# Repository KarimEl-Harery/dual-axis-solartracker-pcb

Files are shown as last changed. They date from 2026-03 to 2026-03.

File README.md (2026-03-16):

# Dual Axis Solar Tracker PCB

This repository contains the **PCB design and electronics for a mobile IoT-monitored dual-axis solar tracking system**.

The system automatically aligns a photovoltaic panel with the position of the sun to maximize solar energy generation.

The project combines **mechanical design, embedded systems, PCB development, and IoT communication**.

---

# 📄 Paper

The full project description is available in the paper:

➡️ **[Read the Paper](EMS-Gruppe%2016_STRZYZEWSKI_GAJIC_EL-Harery.pdf)**

---

# 🛰 Solar Tracker System

<p align="center">
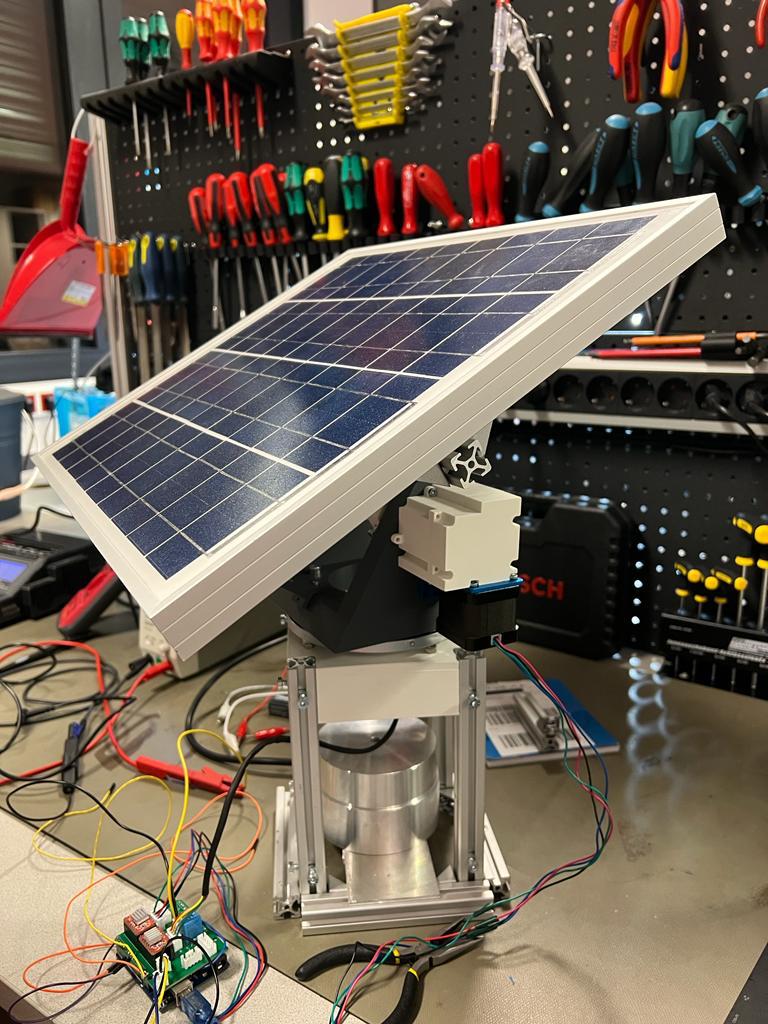
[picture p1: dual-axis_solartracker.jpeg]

</p>

The system uses an **Arduino Uno WiFi Rev2** to calculate the sun position based on GPS data and automatically align the photovoltaic panel using two motorized axes:

- **Azimuth rotation**
- **Altitude rotation**

The tracker communicates with an **IoT platform via WiFi using MQTT**.

---

# 🔌 PCB Design

The project includes a custom **Arduino Shield PCB** which integrates:

- Stepper motor control
- Sensor interfaces (light, temperature, GPS)
- Power management
- Communication interfaces

<p align="center">
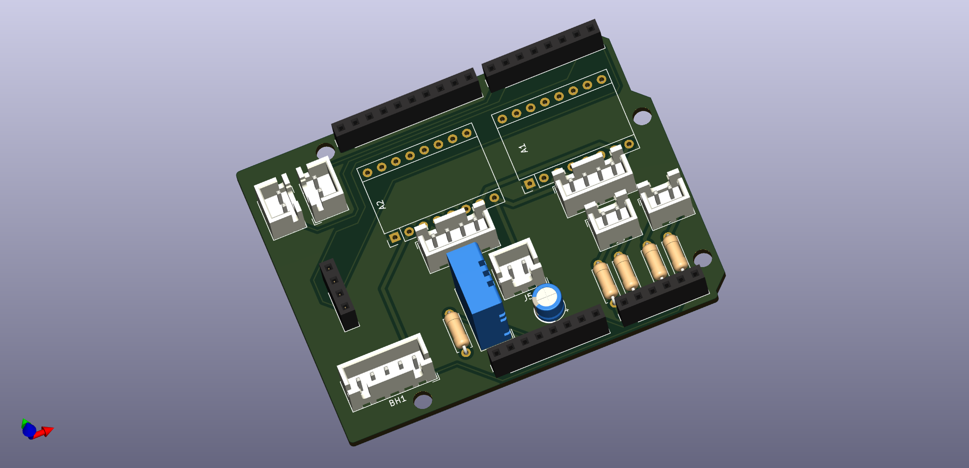
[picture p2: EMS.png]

</p>

---

# ⚙️ System Architecture

The solar tracker consists of three main subsystems:

### Embedded Control

- Arduino Uno WiFi Rev2
- Sun position calculation via library
- Stepper motor control
- Sensor data acquisition

### Electronics

Custom PCB providing:

- Motor driver interfaces
- Sensor connections
- GPS interface
- Power distribution

### Mechanical System

- **3D printed planetary gearbox** for altitude motion
- **Worm gear transmission** for azimuth motion
- Mobile solar platform

---

# 🌐 IoT Monitoring

System data is transmitted to an IoT platform via **WiFi using MQTT**.

Monitored parameters include:

- GPS position
- Solar panel orientation
- Illumination data
- Temperature
- System status

---

# 🔋 Power System

The system is powered by a **3S Li-Po battery (11.1V)** which is charged by the photovoltaic panel.

---

# 👨‍🔬 Authors  
Karim El-Harery

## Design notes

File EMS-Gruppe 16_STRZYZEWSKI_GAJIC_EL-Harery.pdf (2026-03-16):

# Mobiles IoT-überwachtes Solartracking-System

Patryk Strzyzewski, Milos Gajic, Karim El-Harery Fakultät Industrial Engineering, FH Technikum Wien, 1200 Wien

## Ergebnisse:

- Mobile Dual-Axis-Solar-Tracking-System
- 11,1V Lipo-Akku mit 3S-Konfiguration wird aufgeladen
- Aktueller Standort über GPS → Berechnung der Sonnenposition
- Steuerungen der Schrittmotoren über Arduino Uno Wifi Rev2
- Vertikale Drehung → 3D-gedrucktes Planetengetriebe
- Horizontale Drehung → Schneckengetriebe

## Einführung:

“Solar tracking system is a combination of electronics and mechanical system for aligning the Photovoltaic (PV) panels to the position of the sun [1]. ”

## Methoden:

## Ausblick:

Zu verbessern ist, dass ein Haltemoment mechanisch für die Azimut realisiert werden kann, damit es auch windresistent ist. Außerdem ist das Printed-Circuit-Board zu optimieren und neu herzustellen, da sie einige Fehler enthielt, diese wurden vorrübergehend mit Kabel gelöst. In Zukunft müsste auch die Schutzklasse erhöht werden. Statt Referenzschaltern, sind Encoder auch eine Möglichkeit, da dadurch die Position noch genauer bestimmbar ist [2].

Referenzen:
[1] J. F. Lee and N. A. Rahim, “Performance comparison of dual-axis solar tracker vs static solar system in Malaysia,” in 2013 IEEE Conference on Clean Energy and Technology (CEAT), Lankgkawi, Malaysia, 2013, pp. 102–107.
[2] KC Kim Consulting GmbH, “Encoder,” in . Accessed: Jan. 16 2024. [Online]. Available: https://www.kcco.com/de/glossar/encoder/

Konstruktion &
Getriebe

Daten in IoT-Plattform
Arduino Shield

Motorsteuerung

Sensorschnittstellen
(Belichtung, Temperatur,
GPS)

Arduino Uno Wifi-Rev-2

Sonnenberechnung über
Library

Verbindung über Wlan mit
MQTT

Azimuth-Bewegung

Altitude-Bewegung

Abb.2 Solartracker-Konstruktion

Abb.1 Programmtechnischer Prozessablauf des Solartracking-System

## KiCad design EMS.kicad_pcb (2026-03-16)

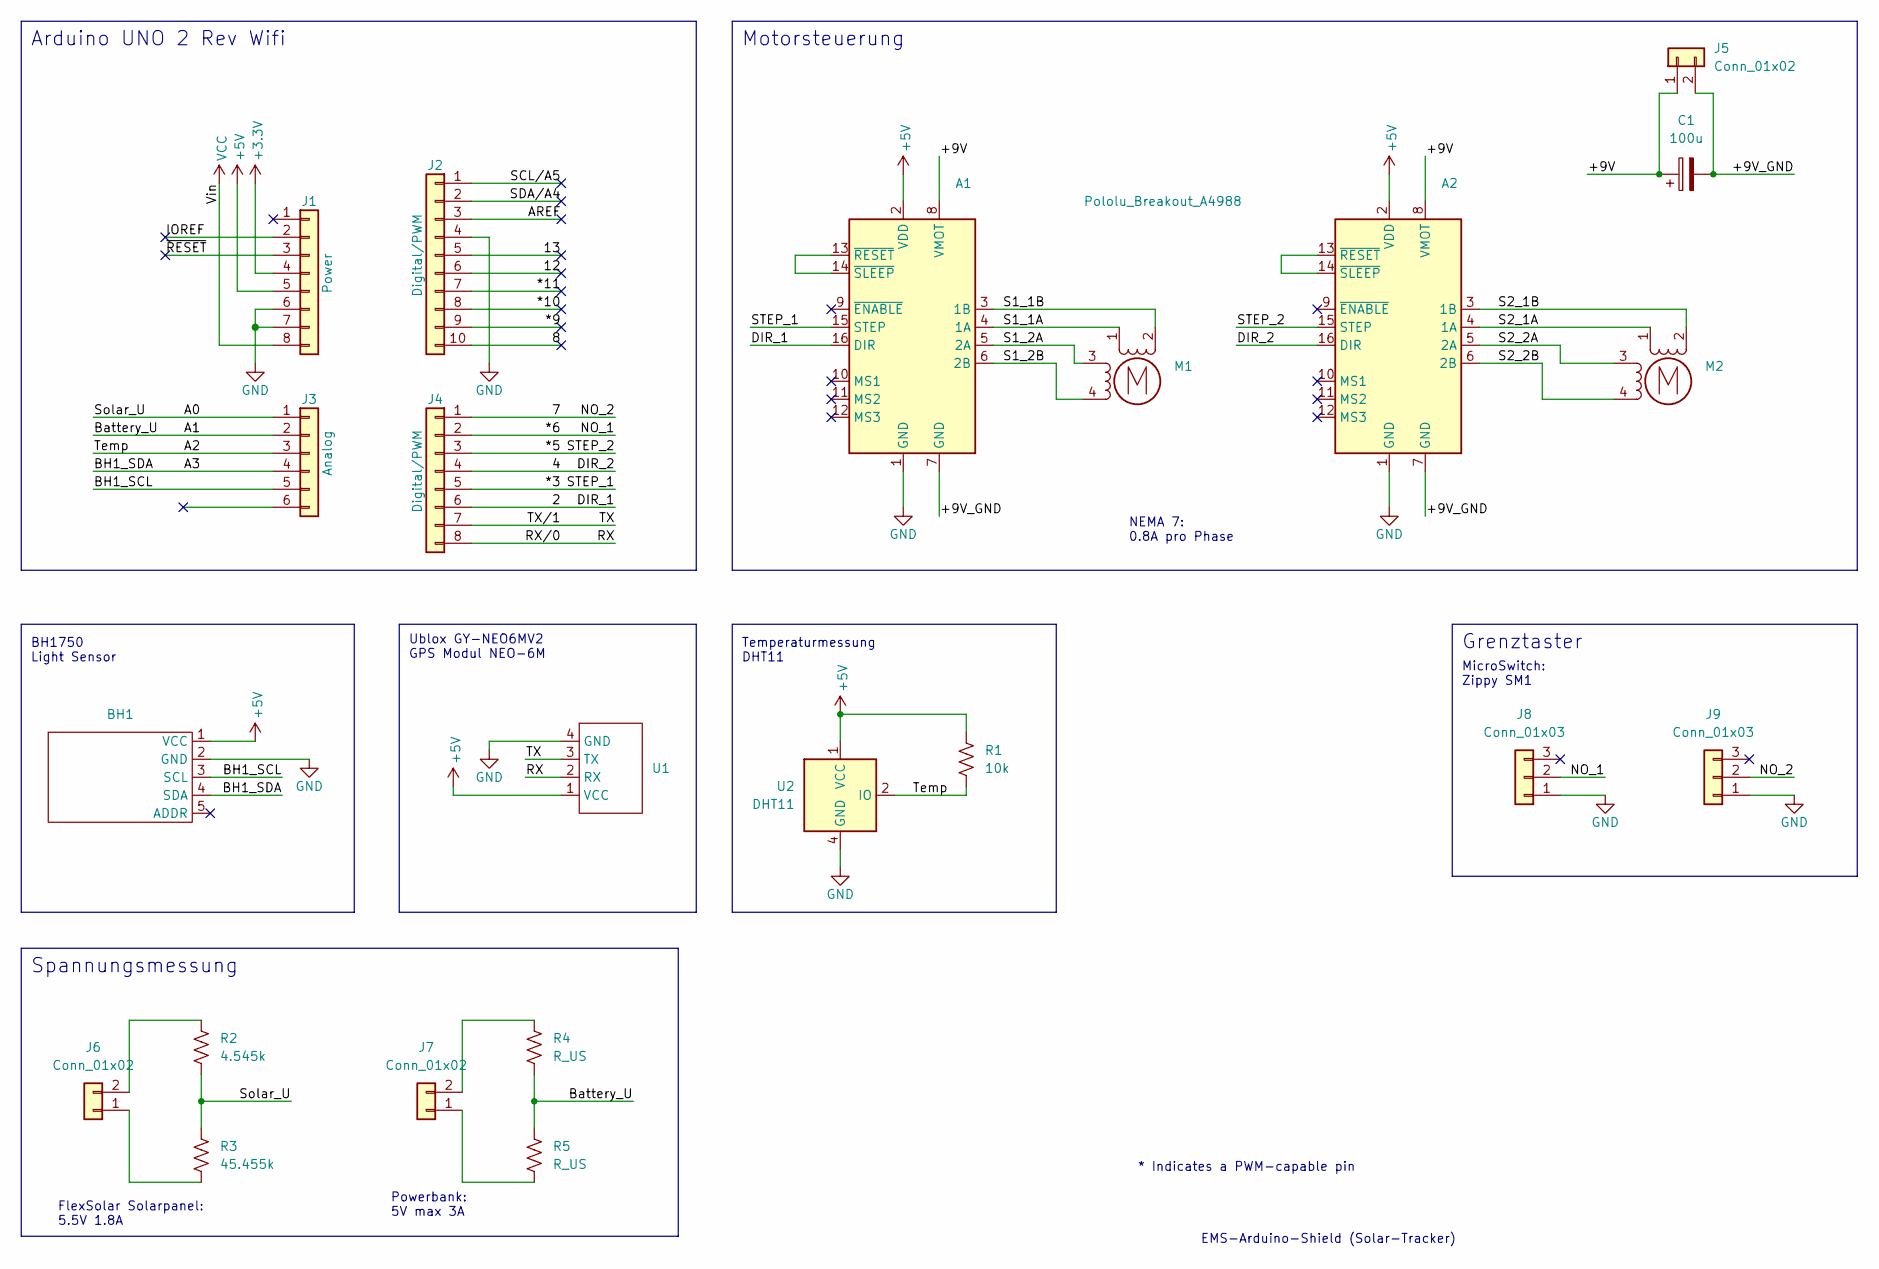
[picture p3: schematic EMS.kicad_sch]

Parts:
A1, A2: Pololu_Breakout_A4988; Pololu_Breakout-16_15.2x20.3mm
BH1: JST_XH_B5B-XH-A_1x05_P2.50mm_Vertical
C1: 100u; CP_Radial_D5.0mm_P2.50mm
J1: Power; PinSocket_1x08_P2.54mm_Vertical
J2: Digital/PWM; PinSocket_1x10_P2.54mm_Vertical
J3: Analog; PinSocket_1x06_P2.54mm_Vertical
J4: Digital/PWM; PinSocket_1x08_P2.54mm_Vertical
J5, J6, J7: Conn_01x02; JST_XH_B2B-XH-A_1x02_P2.50mm_Vertical
J8, J9: Conn_01x03; JST_XH_B2B-XH-A_1x02_P2.50mm_Vertical
M1, M2: Stepper_Motor_bipolar; JST_XH_B4B-XH-A_1x04_P2.50mm_Vertical
R1: 10k; R_Axial_DIN0207_L6.3mm_D2.5mm_P7.62mm_Horizontal
R2: 4.545k; R_Axial_DIN0207_L6.3mm_D2.5mm_P7.62mm_Horizontal
R3: 45.455k; R_Axial_DIN0207_L6.3mm_D2.5mm_P7.62mm_Horizontal
R4, R5: R_US; R_Axial_DIN0207_L6.3mm_D2.5mm_P7.62mm_Horizontal
U1: PinSocket_1x04_P2.54mm_Vertical
U2: DHT11; Aosong_DHT11_5.5x12.0_P2.54mm

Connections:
+3V3: J1.4
+5V: A1.2 (VDD), A2.2 (VDD), BH1.1 (VCC), J1.5, R1.1, U1.1 (VCC), U2.1 (VCC)
/2: A1.16 (DIR), J4.6
/4: A2.16 (DIR), J4.4
/7: J4.1, J9.2
/8: J2.10
/12: J2.6
/13: J2.5
/*3: A1.15 (STEP), J4.5
/*5: A2.15 (STEP), J4.3
/*6: J4.2, J8.2
/*9: J2.9
/*10: J2.8
/*11: J2.7
/+9V: A1.8 (VMOT), A2.8 (VMOT), C1.1, J5.1
/+9V_GND: A1.7 (GND), A2.7 (GND), C1.2, J5.2
/A0: J3.1, R2.2, R3.1
/A1: J3.2, R4.2, R5.1
/A2: J3.3, R1.2, U2.2 (IO)
/A3: BH1.4 (SDA), J3.4
/AREF: J2.3
/BH1_SCL: BH1.3 (SCL), J3.5
/IOREF: J1.2
/RX: J4.8, U1.2 (RX)
/S1_1A: A1.4 (1A), M1.1
/S1_1B: A1.3 (1B), M1.2 (-)
/S1_2A: A1.5 (2A), M1.3
/S1_2B: A1.6 (2B), M1.4
/S2_1A: A2.4 (1A), M2.1
/S2_1B: A2.3 (1B), M2.2 (-)
/S2_2A: A2.5 (2A), M2.3
/S2_2B: A2.6 (2B), M2.4
/SCL/A5: J2.1
/SDA/A4: J2.2
/TX: J4.7, U1.3 (TX)
/~RESET: J1.3
GND: A1.1 (GND), A2.1 (GND), BH1.2 (GND), J1.6, J1.7, J2.4, J8.1, J9.1, U1.4 (GND), U2.4 (GND)
unnamed: A1.13 (~RESET), A1.14 (~SLEEP)
unnamed: A2.13 (~RESET), A2.14 (~SLEEP)
unnamed: J6.1, R3.2
unnamed: J6.2, R2.1
unnamed: J7.1, R5.2
unnamed: J7.2, R4.1
VCC: J1.8

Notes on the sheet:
BH1750 Light Sensor
Temperaturmessung DHT11
EMS-Arduino-Shield (Solar-Tracker)
MicroSwitch: Zippy SM1
Spannungsmessung
FlexSolar Solarpanel: 5.5V 1.8A
Ublox GY-NEO6MV2 GPS Modul NEO-6M
NEMA 7: 0.8A pro Phase
Powerbank: 5V max 3A
Motorsteuerung
Arduino UNO 2 Rev Wifi
* Indicates a PWM-capable pin
Grenztaster

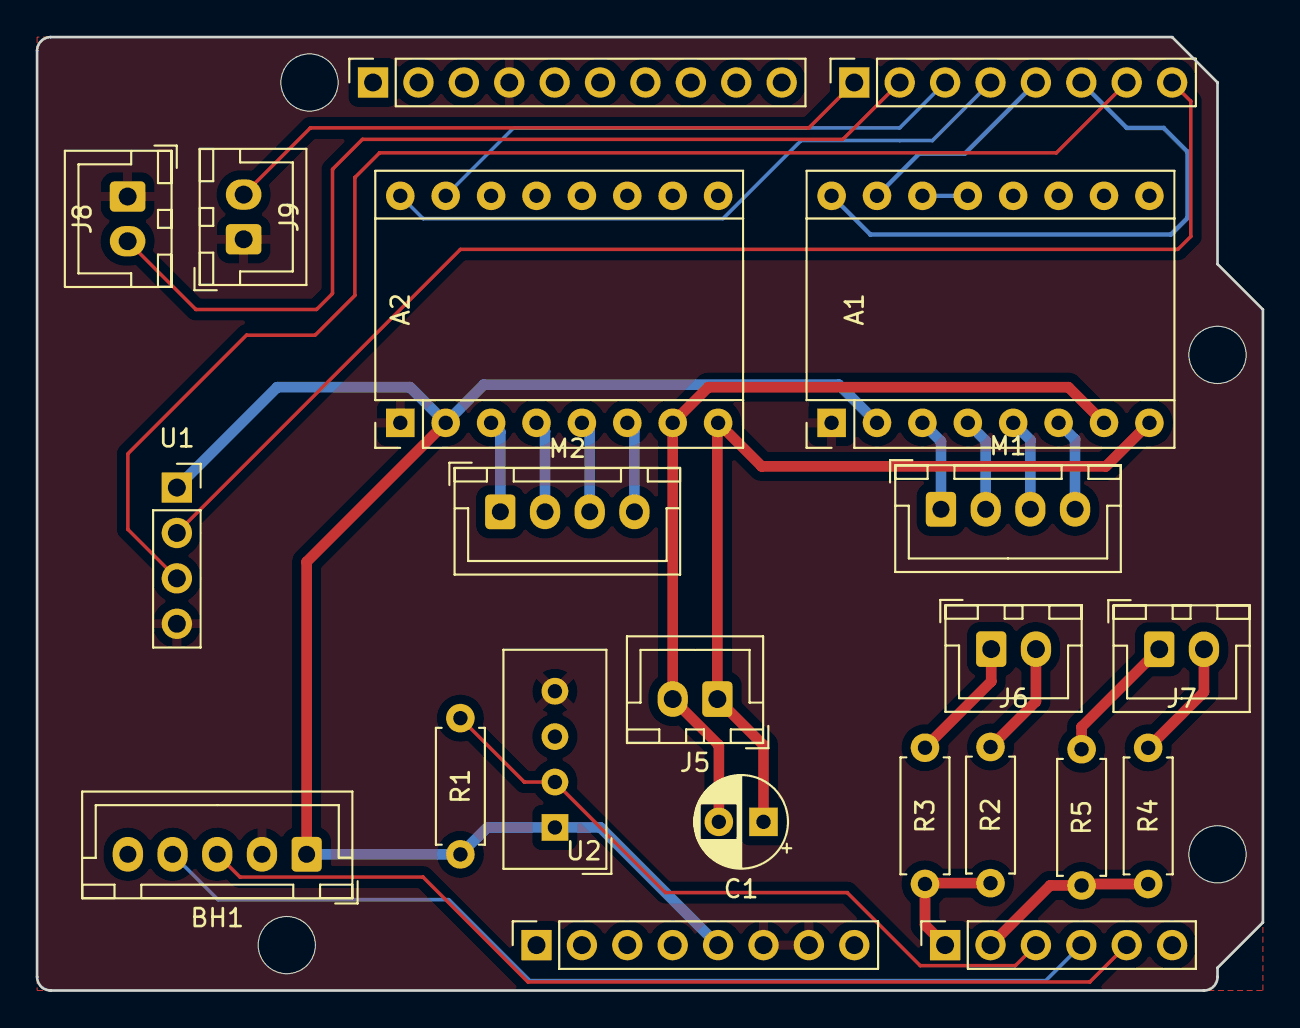
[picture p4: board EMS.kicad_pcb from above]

Board: 2 copper layers, 68.6 x 53.3 mm, 26 parts (0 on the bottom side), 31 nets.

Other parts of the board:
MH1, MH2, MH3, MH4: MountingHole_3.2mm
